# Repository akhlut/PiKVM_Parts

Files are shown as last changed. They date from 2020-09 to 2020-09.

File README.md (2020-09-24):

# PiKVM_Parts

Parts I've made for the PiKVM Project.  https://github.com/pikvm/pikvm

All parts are UNTESTED as of 9/23/2020

The idea behind this is to extend the core PiKVM and turn it into a 4-port switch.  4-Port HDMI switches are ubiquitous and inexpensive, making them a less than ideal candidate for designing a PCB around.  Given that GPIO pins can be assigned to specific functions it only makes sense to start building out a 4-port USB/ATX controller built on top of PiKVM.  Couple this with a way to mimic a button-press on an HDMI switch and we're in business.  

The USB and ATX PCB's stack on top of one another, minimizing the footprint.  The PCB's extend the width of the Pi, but not the length.  At some point I'll have to design a case.

Everything is drawn in EAGLE as it's the tool that I'm used to.

Questions?  
Ask on the discord server:  https://discord.com/channels/580094191938437144

Ask on the subreddit: https://old.reddit.com/r/pikvm/

Happy soldering!

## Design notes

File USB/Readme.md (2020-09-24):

PiKVM USB splitter design notes

AS OF 09232020 THIS DESIGN IS COMPLETE BUT UNTESTED!!!

This design uses Analog Devices ADUM3160 iCouplers to provide galvanic isolation between the OTG USB and the (4) external USB ports.

The GPIO pinout (v1.6) is as follows:

PORT A

    GPIO 17

PORT B

    GPIO 24

PORT C

    GPIO 11

PORT D

    GPIO 13

The OTG port can be switched to Ports A-D by holding GPIO HIGH.  

The OTG port does NOT supply power to the Raspberry Pi!  

Power the Pi by either: 

(1) Use the POWER-IN Port on the PCB to supply 5V to the PCB and Pi via the GPIO header

OR

(2) Use a POE hat to power the PI and use jumper cables to power the PCB @ AUX_PWR header

NEVER USE BOTH POWER OPTIONS AT ONCE!

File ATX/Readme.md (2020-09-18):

PiKVM ATX controller design notes

This design uses RJ45 connectors as they are cheap, compact, and ubiquitous.

The RJ45 pinout (v1.5) uses the T-568B pattern and is as follows:

    PIN_1 : W-O : POWER LED +

    PIN_2 : O-W : POWER LED -

    PIN_3 : W-G : IDE LED -

    PIN_4 : Bl-W : RESET -

    PIN_5 : W-Bl : RESET +

    PIN_6 : G-W : IDE LED +

    PIN_7 : W-Br : POWER +

    PIN_8 : Br-W : POWER -

-----

The GPIO pinout (v1) is as follows:

PORT A

    GPIO 03 - POWER

    GPIO 15 - RESET

    GPIO 04 - POWER LED

    GPIO 14 - IDE LED

PORT B

    GPIO 18 - POWER

    GPIO 27 - RESET

    GPIO 22 - POWER LED

    GPIO 23 - IDE LED

PORT C

    GPIO 10 - POWER

    GPIO 08 - RESET

    GPIO 09 - POWER LED

    GPIO 25 - IDE LED

PORT D

    GPIO 07 - POWER

    GPIO 06 - RESET

    GPIO 12 - POWER LED

    GPIO 05 - IDE LED

---

There is also a port to control an external switch.  A DC barrel jack is provided for connectivity.  There is no polarity, simply Common/Normally Open.  This is useful to control external HDMI/KVM switches.

EXTERNAL CONTROL PORT - GPIO 21

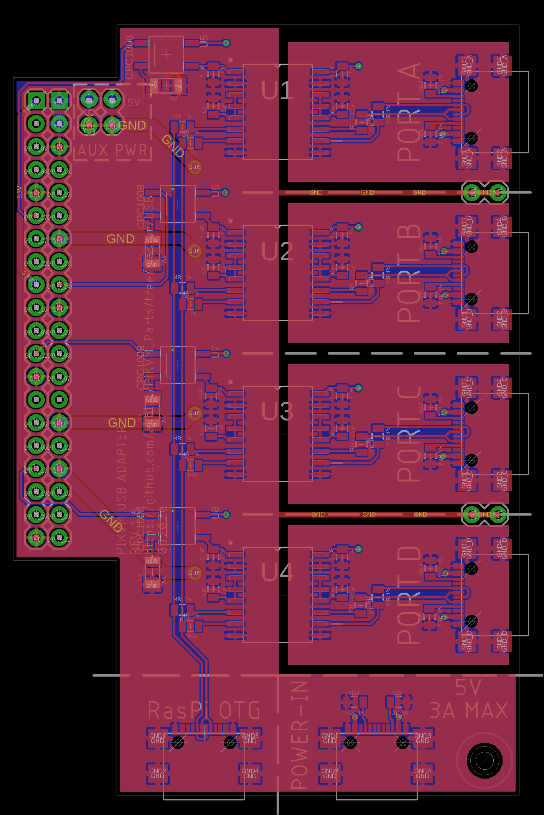
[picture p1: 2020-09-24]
USB/PiKVM_USB_Adapter v1.6.png

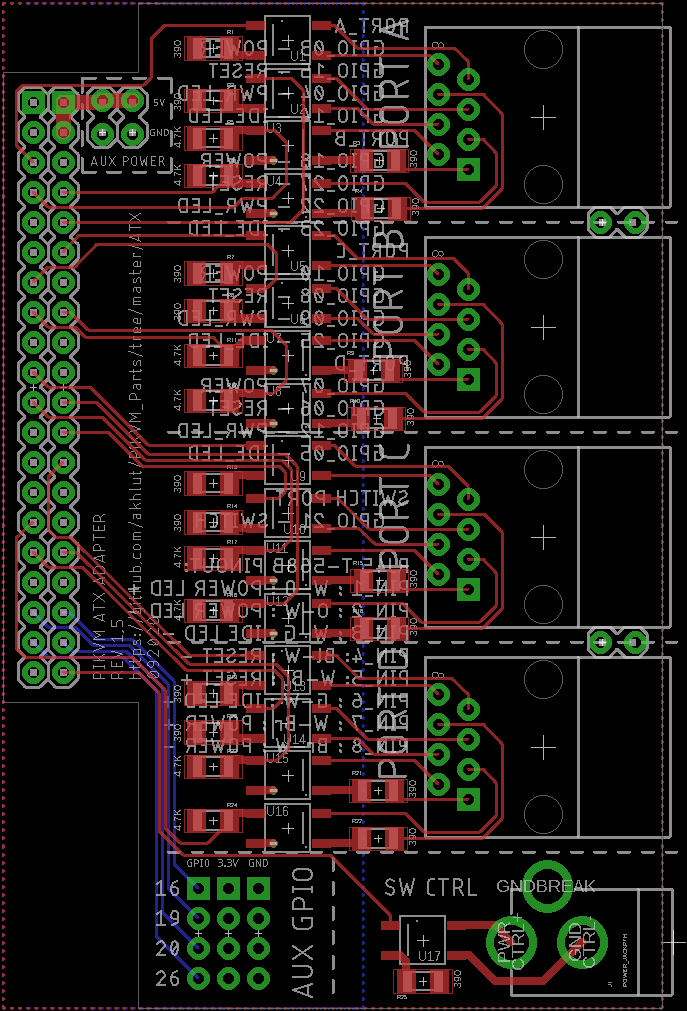
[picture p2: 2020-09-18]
ATX/PiKVM ATX Adapter v1.5.png

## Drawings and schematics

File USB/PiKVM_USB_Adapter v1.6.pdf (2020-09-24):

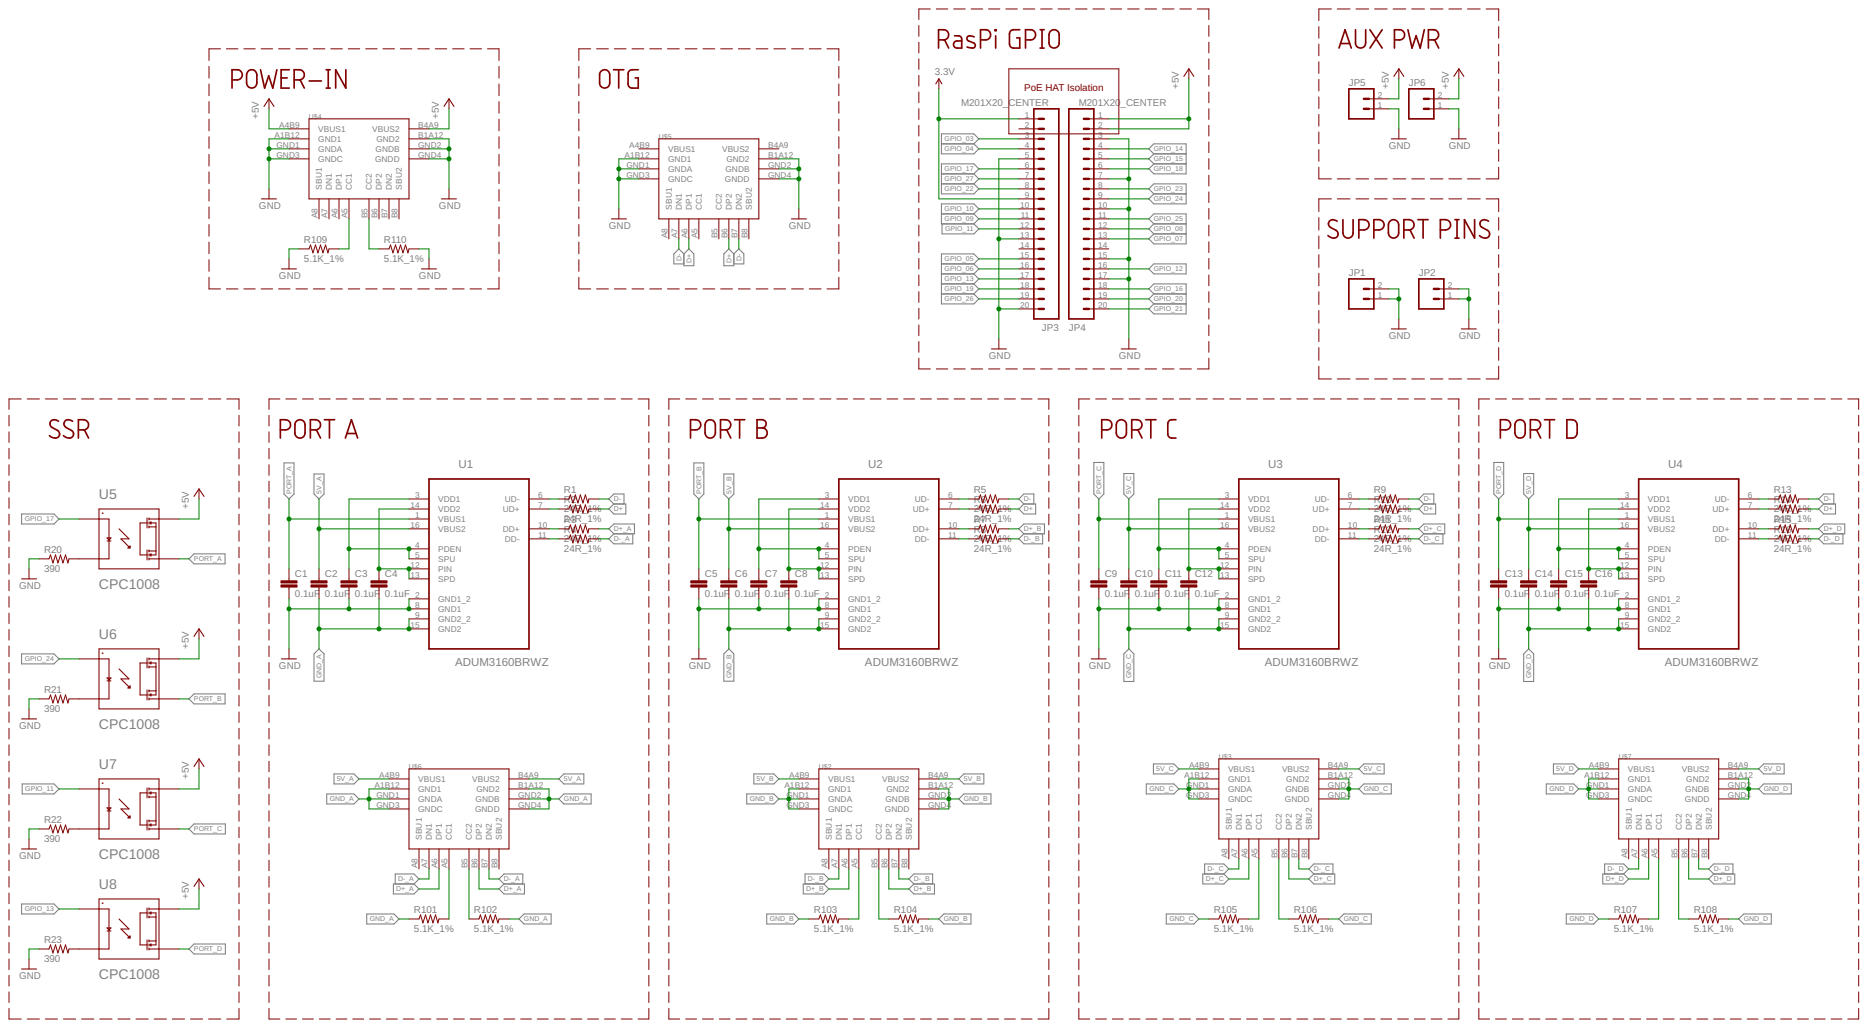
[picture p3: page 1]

10 | 10
11 | 11
12 | 12
13 | 13
14 | 14

16 | 16
17 | 17

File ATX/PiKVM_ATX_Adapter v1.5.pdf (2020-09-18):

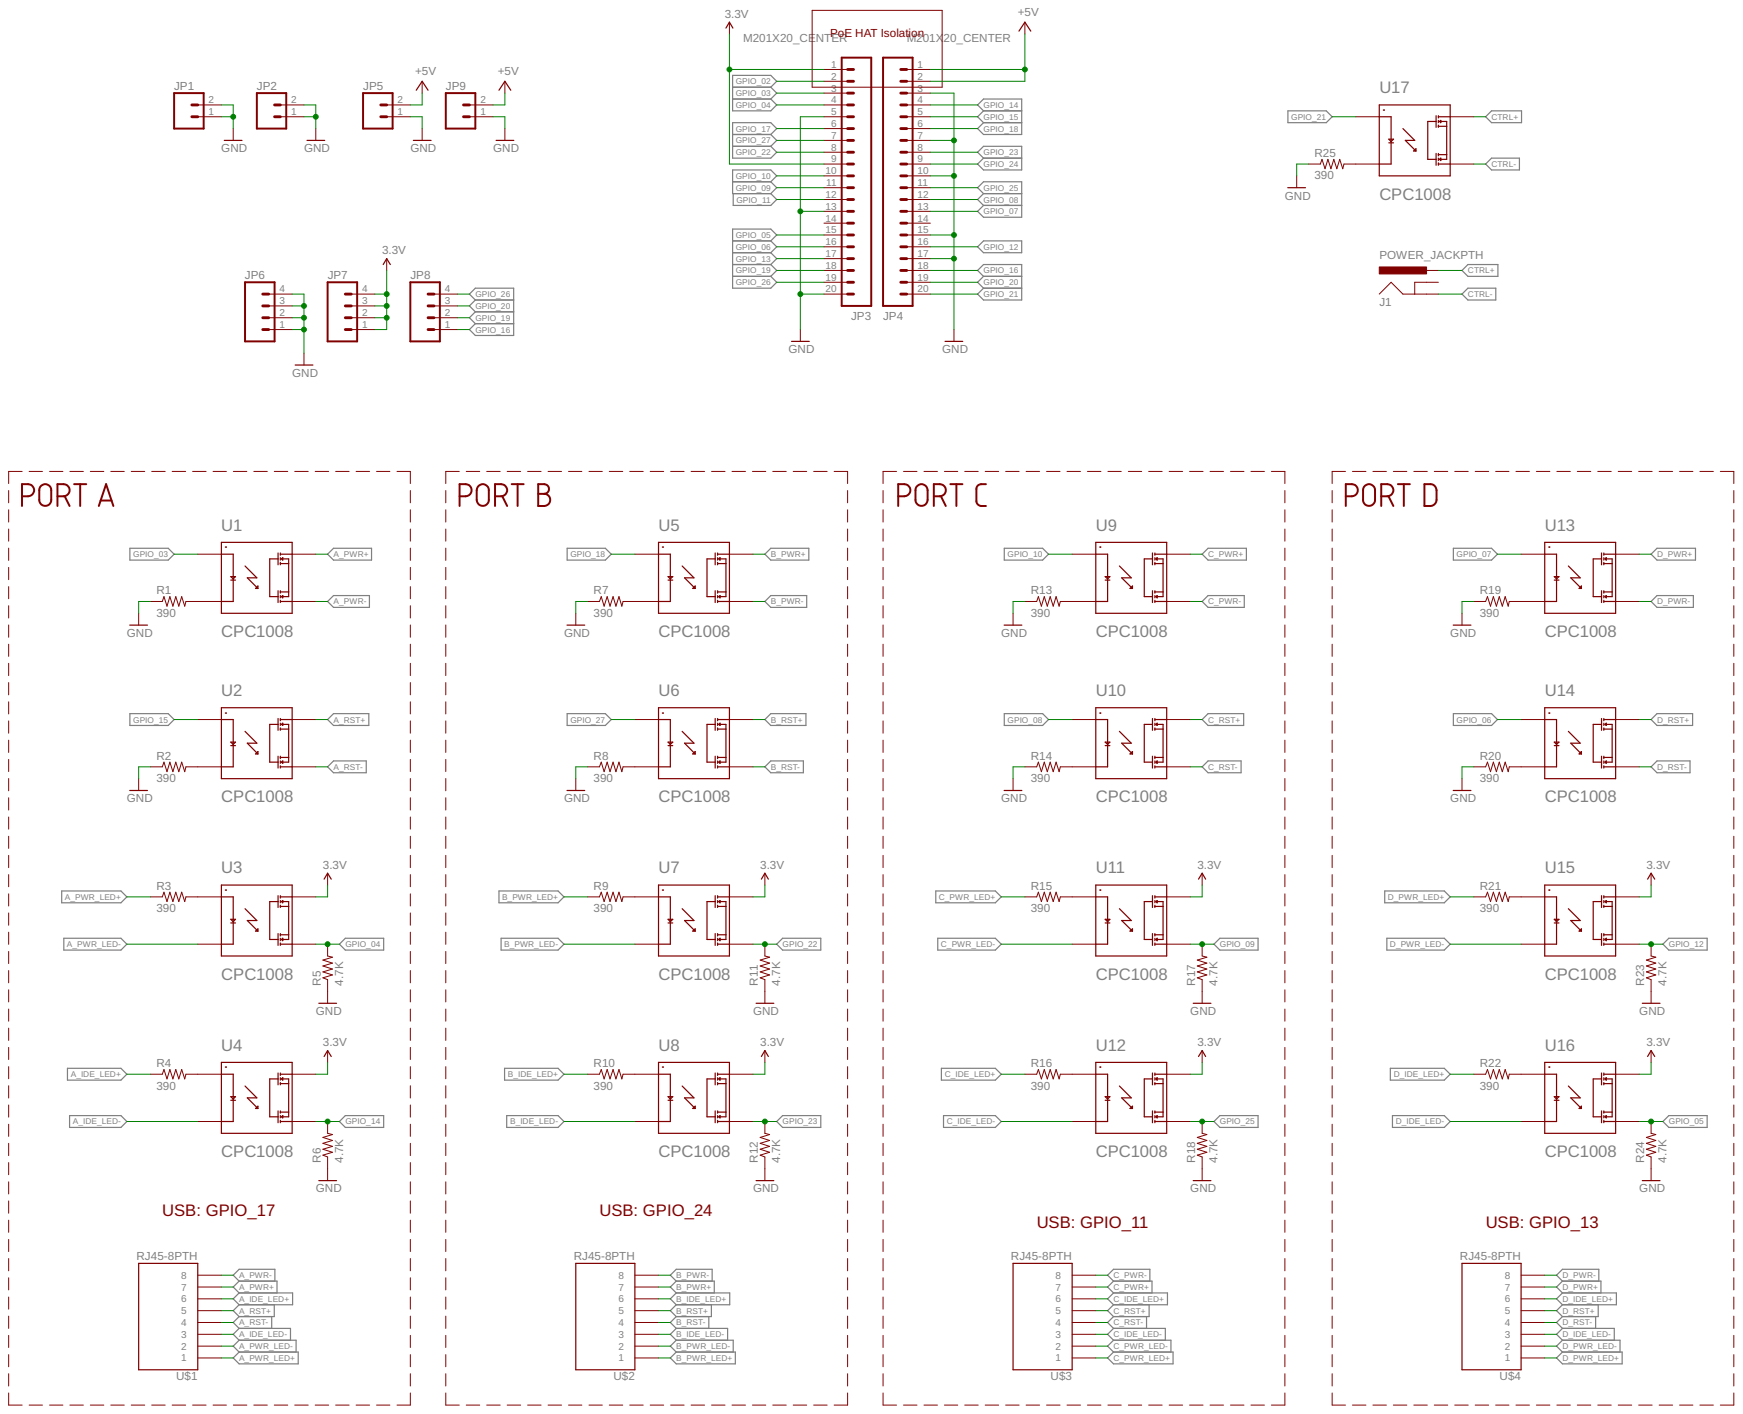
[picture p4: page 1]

13 | GPIO_08 GPIO_07

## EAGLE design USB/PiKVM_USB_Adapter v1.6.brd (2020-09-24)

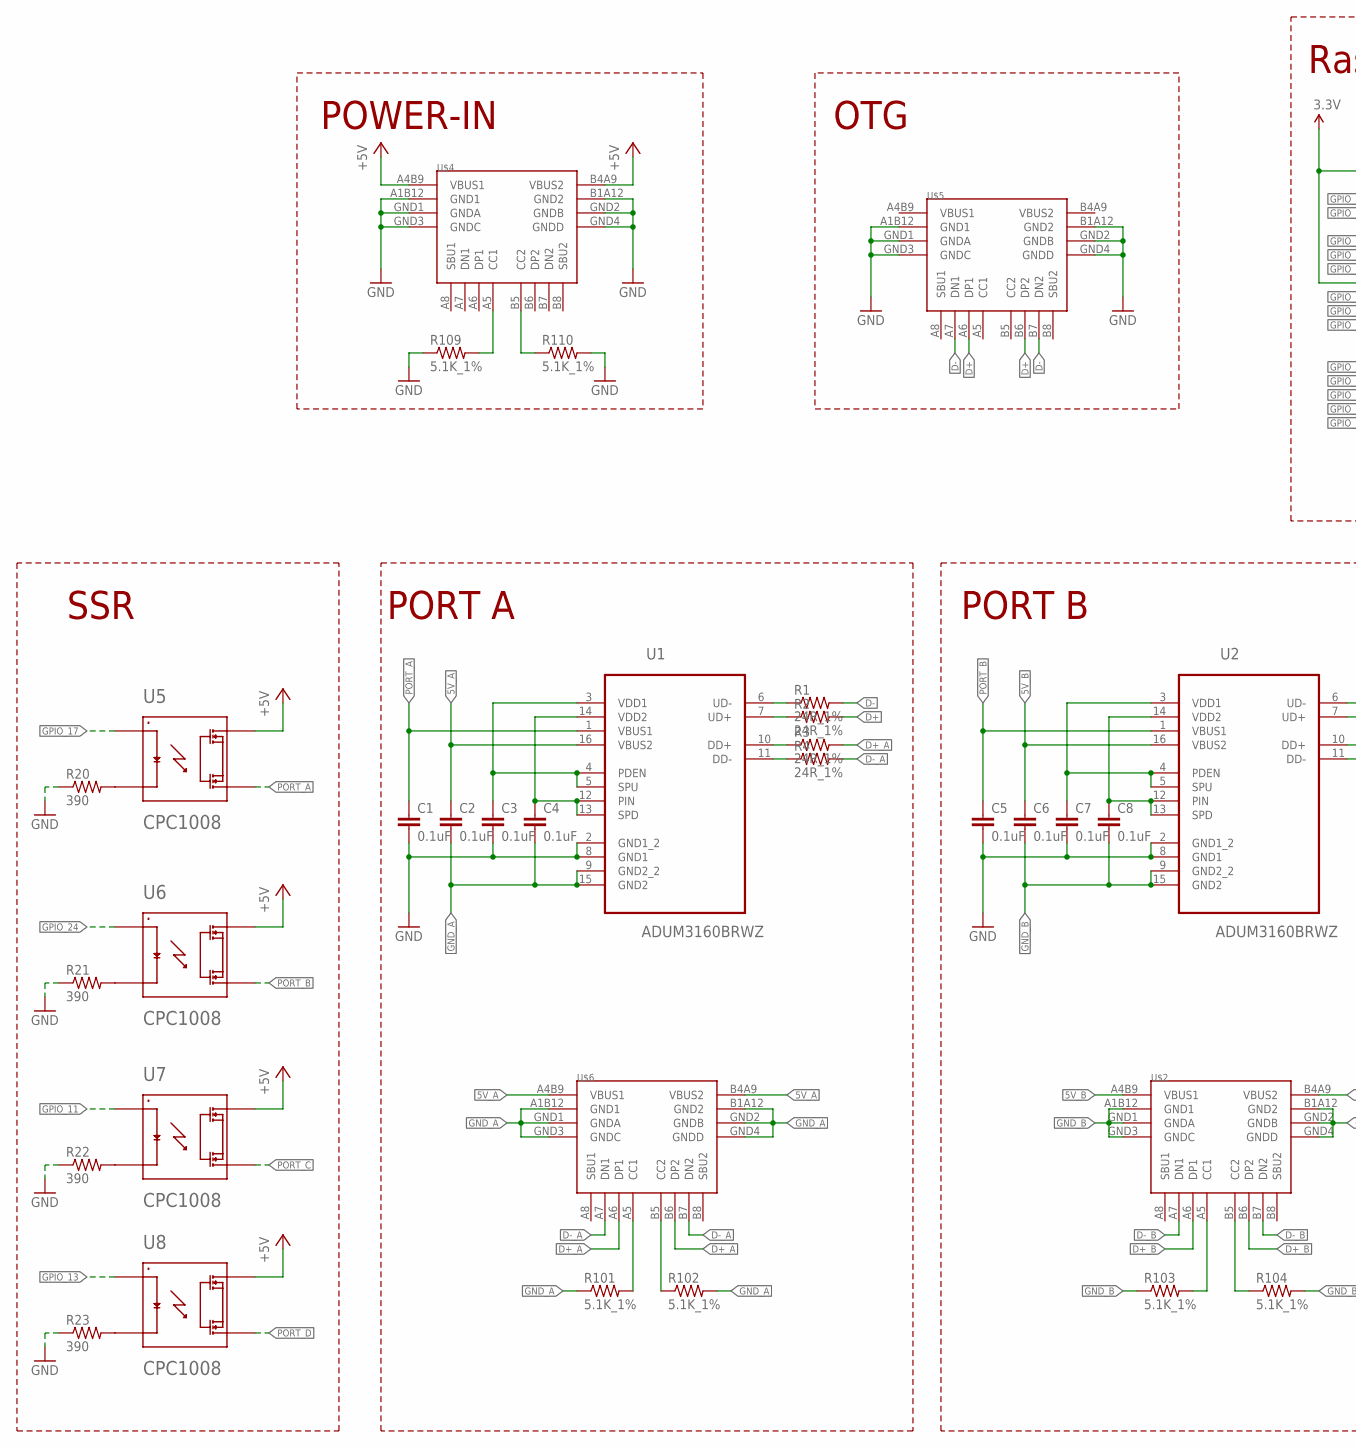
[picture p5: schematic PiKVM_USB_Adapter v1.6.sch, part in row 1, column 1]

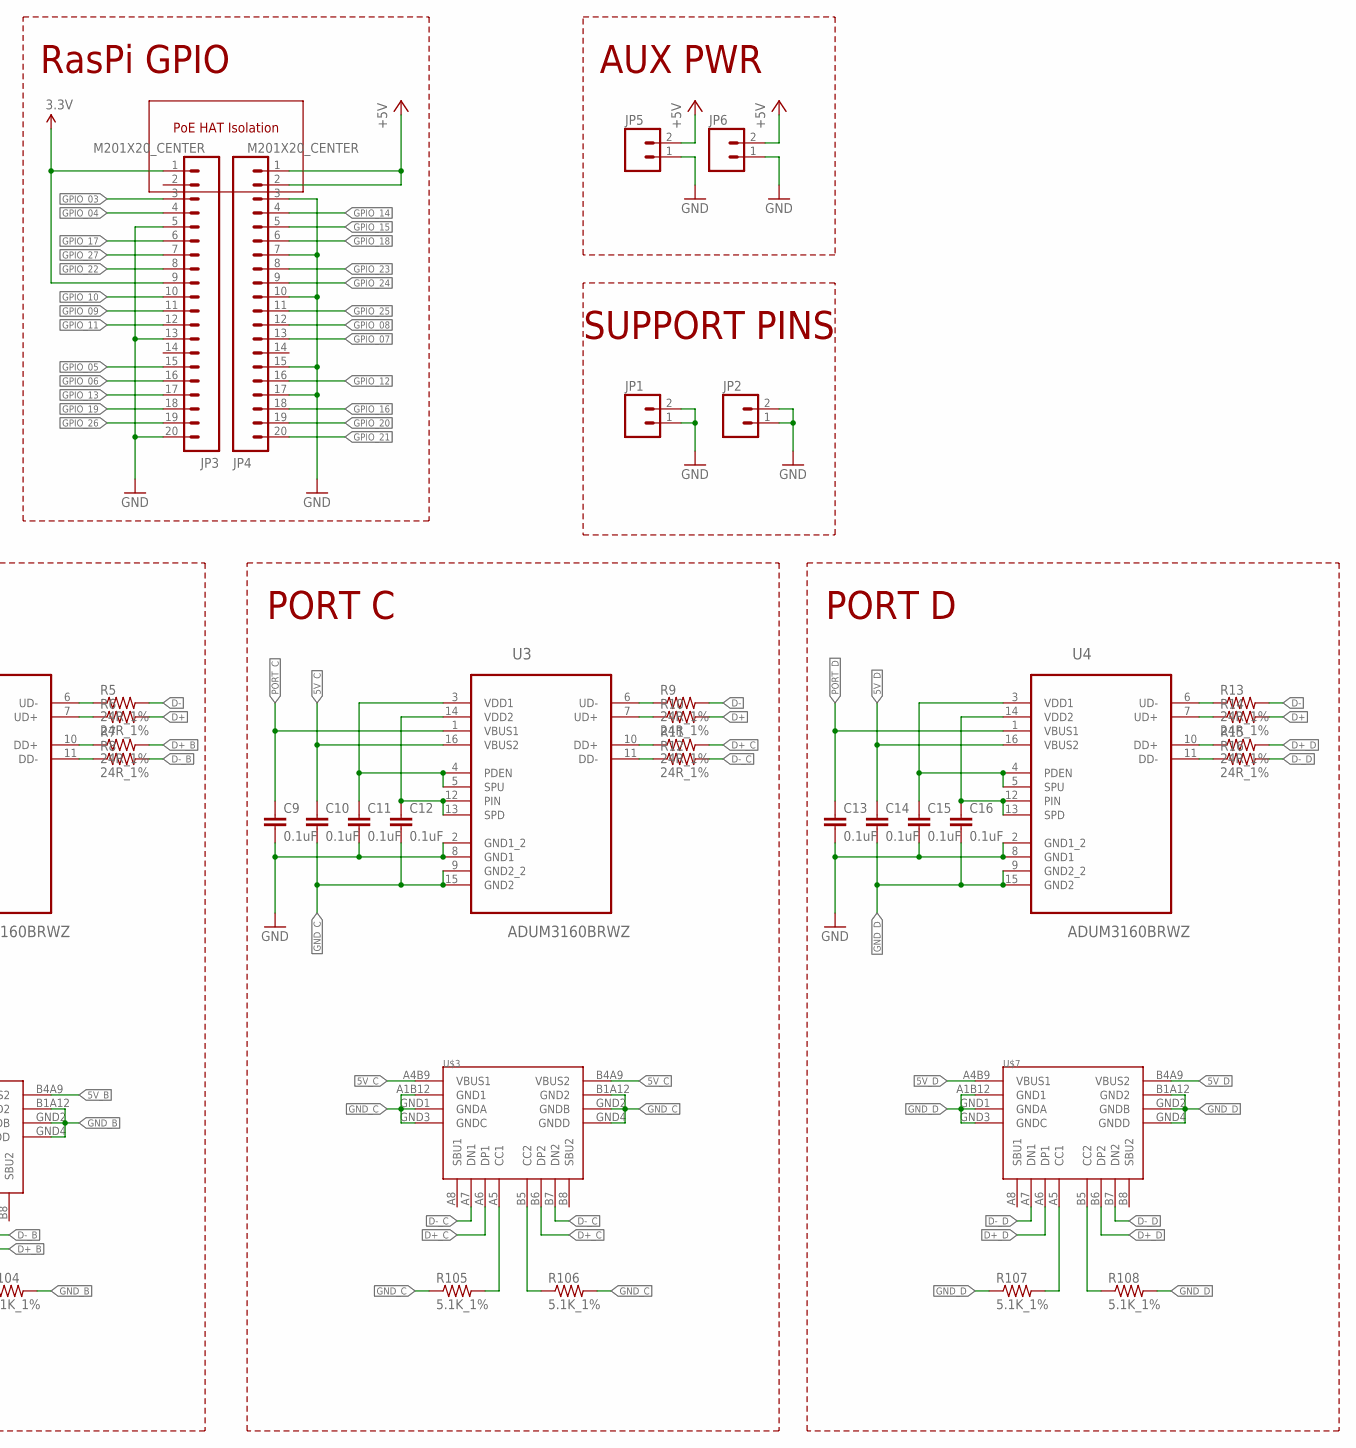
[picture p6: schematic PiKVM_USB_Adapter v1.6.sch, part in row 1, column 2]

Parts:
C1, C2, C3, C4, C5, C6, C7, C8, C9, C10, C11, C12, C13, C14, C15, C16: 0.1uF; 0805
JP1, JP2, JP5, JP6: M02LOCK; 1X02_LOCK
JP3, JP4: M201X20_CENTER; 1X20_CENTER
R1, R2, R3, R4, R5, R6, R7, R8, R9, R10, R11, R12, R13, R14, R15, R16: 24R_1%; 0805
R20, R21, R22, R23: 390; 1206
R101, R102, R103, R104, R105, R106, R107, R108, R109, R110: 5.1K_1%; 0805
U1, U2, U3, U4: ADUM3160BRWZ; SOIC127P1032X265-16N
U5, U6, U7, U8: CPC1008; SOP-4
U$2, U$3, U$4, U$5, U$6, U$7: USB4110GFA; GCT_USB4110GFA

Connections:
3.3V: JP3.1, JP3.9
5V_A: C2.1, U1.16 (VBUS2), U$6.A4B9 (VBUS1), U$6.B4A9 (VBUS2)
5V_B: C6.1, U2.16 (VBUS2), U$2.A4B9 (VBUS1), U$2.B4A9 (VBUS2)
5V_C: C10.1, U3.16 (VBUS2), U$3.A4B9 (VBUS1), U$3.B4A9 (VBUS2)
5V_D: C14.1, U4.16 (VBUS2), U$7.A4B9 (VBUS1), U$7.B4A9 (VBUS2)
+5V: JP4.1, JP4.2, JP5.2, JP6.2, U5.P$4 (4), U6.P$4 (4), U7.P$4 (4), U8.P$4 (4), U$4.A4B9 (VBUS1), U$4.B4A9 (VBUS2)
D+: R2.2, R6.2, R10.2, R14.2, U$5.A6 (DP1), U$5.B6 (DP2)
D+_A: R3.2, U$6.A6 (DP1), U$6.B6 (DP2)
D+_B: R7.2, U$2.A6 (DP1), U$2.B6 (DP2)
D+_C: R11.2, U$3.A6 (DP1), U$3.B6 (DP2)
D+_D: R15.2, U$7.A6 (DP1), U$7.B6 (DP2)
D-: R1.2, R5.2, R9.2, R13.2, U$5.A7 (DN1), U$5.B7 (DN2)
D-_A: R4.2, U$6.A7 (DN1), U$6.B7 (DN2)
D-_B: R8.2, U$2.A7 (DN1), U$2.B7 (DN2)
D-_C: R12.2, U$3.A7 (DN1), U$3.B7 (DN2)
D-_D: R16.2, U$7.A7 (DN1), U$7.B7 (DN2)
GND: C1.2, C3.2, C5.2, C7.2, C9.2, C11.2, C13.2, C15.2, JP1.1, JP1.2, JP2.1, JP2.2, JP3.5, JP3.13, JP3.20, JP4.3, JP4.7, JP4.10, JP4.15, JP4.17, JP5.1, JP6.1, R20.1, R21.1, R22.1, R23.1, R109.1, R110.2, U1.2 (GND1_2), U1.8 (GND1), U2.2 (GND1_2), U2.8 (GND1), U3.2 (GND1_2), U3.8 (GND1), U4.2 (GND1_2), U4.8 (GND1), U$4.A1B12 (GND1), U$4.B1A12 (GND2), U$4.GND1 (GNDA), U$4.GND2 (GNDB), U$4.GND3 (GNDC), U$4.GND4 (GNDD), U$5.A1B12 (GND1), U$5.B1A12 (GND2), U$5.GND1 (GNDA), U$5.GND2 (GNDB), U$5.GND3 (GNDC), U$5.GND4 (GNDD)
GND_A: C2.2, C4.2, R101.1, R102.2, U1.9 (GND2_2), U1.15 (GND2), U$6.A1B12 (GND1), U$6.B1A12 (GND2), U$6.GND1 (GNDA), U$6.GND2 (GNDB), U$6.GND3 (GNDC), U$6.GND4 (GNDD)
GND_B: C6.2, C8.2, R103.1, R104.2, U2.9 (GND2_2), U2.15 (GND2), U$2.A1B12 (GND1), U$2.B1A12 (GND2), U$2.GND1 (GNDA), U$2.GND2 (GNDB), U$2.GND3 (GNDC), U$2.GND4 (GNDD)
GND_C: C10.2, C12.2, R105.1, R106.2, U3.9 (GND2_2), U3.15 (GND2), U$3.A1B12 (GND1), U$3.B1A12 (GND2), U$3.GND1 (GNDA), U$3.GND2 (GNDB), U$3.GND3 (GNDC), U$3.GND4 (GNDD)
GND_D: C14.2, C16.2, R107.1, R108.2, U4.9 (GND2_2), U4.15 (GND2), U$7.A1B12 (GND1), U$7.B1A12 (GND2), U$7.GND1 (GNDA), U$7.GND2 (GNDB), U$7.GND3 (GNDC), U$7.GND4 (GNDD)
GPIO_03: JP3.3
GPIO_04: JP3.4
GPIO_05: JP3.15
GPIO_06: JP3.16
GPIO_07: JP4.13
GPIO_08: JP4.12
GPIO_09: JP3.11
GPIO_10: JP3.10
GPIO_11: JP3.12, U7.P$1 (1)
GPIO_12: JP4.16
GPIO_13: JP3.17, U8.P$1 (1)
GPIO_14: JP4.4
GPIO_15: JP4.5
GPIO_16: JP4.18
GPIO_17: JP3.6, U5.P$1 (1)
GPIO_18: JP4.6
GPIO_19: JP3.18
GPIO_20: JP4.19
GPIO_21: JP4.20
GPIO_22: JP3.8
GPIO_23: JP4.8
GPIO_24: JP4.9, U6.P$1 (1)
GPIO_25: JP4.11
GPIO_26: JP3.19
GPIO_27: JP3.7
unnamed: C8.1, U2.12 (PIN), U2.13 (SPD), U2.14 (VDD2)
unnamed: R5.1, U2.6 (UD-)
unnamed: R6.1, U2.7 (UD+)
unnamed: R7.1, U2.10 (DD+)
unnamed: R20.2, U5.P$2 (2)
unnamed: R8.1, U2.11 (DD-)
unnamed: C3.1, U1.3 (VDD1), U1.4 (PDEN), U1.5 (SPU)
unnamed: R101.2, U$6.A5 (CC1)
unnamed: C12.1, U3.12 (PIN), U3.13 (SPD), U3.14 (VDD2)
unnamed: R9.1, U3.6 (UD-)
unnamed: R10.1, U3.7 (UD+)
unnamed: R11.1, U3.10 (DD+)
unnamed: R12.1, U3.11 (DD-)
unnamed: R102.1, U$6.B5 (CC2)
unnamed: R108.1, U$7.B5 (CC2)
unnamed: C16.1, U4.12 (PIN), U4.13 (SPD), U4.14 (VDD2)
unnamed: R13.1, U4.6 (UD-)
unnamed: R107.2, U$7.A5 (CC1)
unnamed: C4.1, U1.12 (PIN), U1.13 (SPD), U1.14 (VDD2)
unnamed: R14.1, U4.7 (UD+)
unnamed: R15.1, U4.10 (DD+)
unnamed: R16.1, U4.11 (DD-)
unnamed: R1.1, U1.6 (UD-)
unnamed: R2.1, U1.7 (UD+)
unnamed: R3.1, U1.10 (DD+)
unnamed: R4.1, U1.11 (DD-)
unnamed: R105.2, U$3.A5 (CC1)
unnamed: R106.1, U$3.B5 (CC2)
unnamed: R21.2, U6.P$2 (2)
unnamed: R22.2, U7.P$2 (2)
unnamed: R23.2, U8.P$2 (2)
unnamed: C7.1, U2.3 (VDD1), U2.4 (PDEN), U2.5 (SPU)
unnamed: R104.1, U$2.B5 (CC2)
unnamed: C11.1, U3.3 (VDD1), U3.4 (PDEN), U3.5 (SPU)
unnamed: C15.1, U4.3 (VDD1), U4.4 (PDEN), U4.5 (SPU)
unnamed: R103.2, U$2.A5 (CC1)
unnamed: R109.2, U$4.A5 (CC1)
unnamed: R110.1, U$4.B5 (CC2)
PORT_A: C1.1, U1.1 (VBUS1), U5.P$3 (3)
PORT_B: C5.1, U2.1 (VBUS1), U6.P$3 (3)
PORT_C: C9.1, U3.1 (VBUS1), U7.P$3 (3)
PORT_D: C13.1, U4.1 (VBUS1), U8.P$3 (3)
VBUS1: U$5.A4B9 (VBUS1)
VBUS2: U$5.B4A9 (VBUS2)

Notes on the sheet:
PoE HAT Isolation
PORT A
PORT B
PORT C
PORT D
SSR
RasPi GPIO
OTG
POWER-IN
AUX PWR
SUPPORT PINS

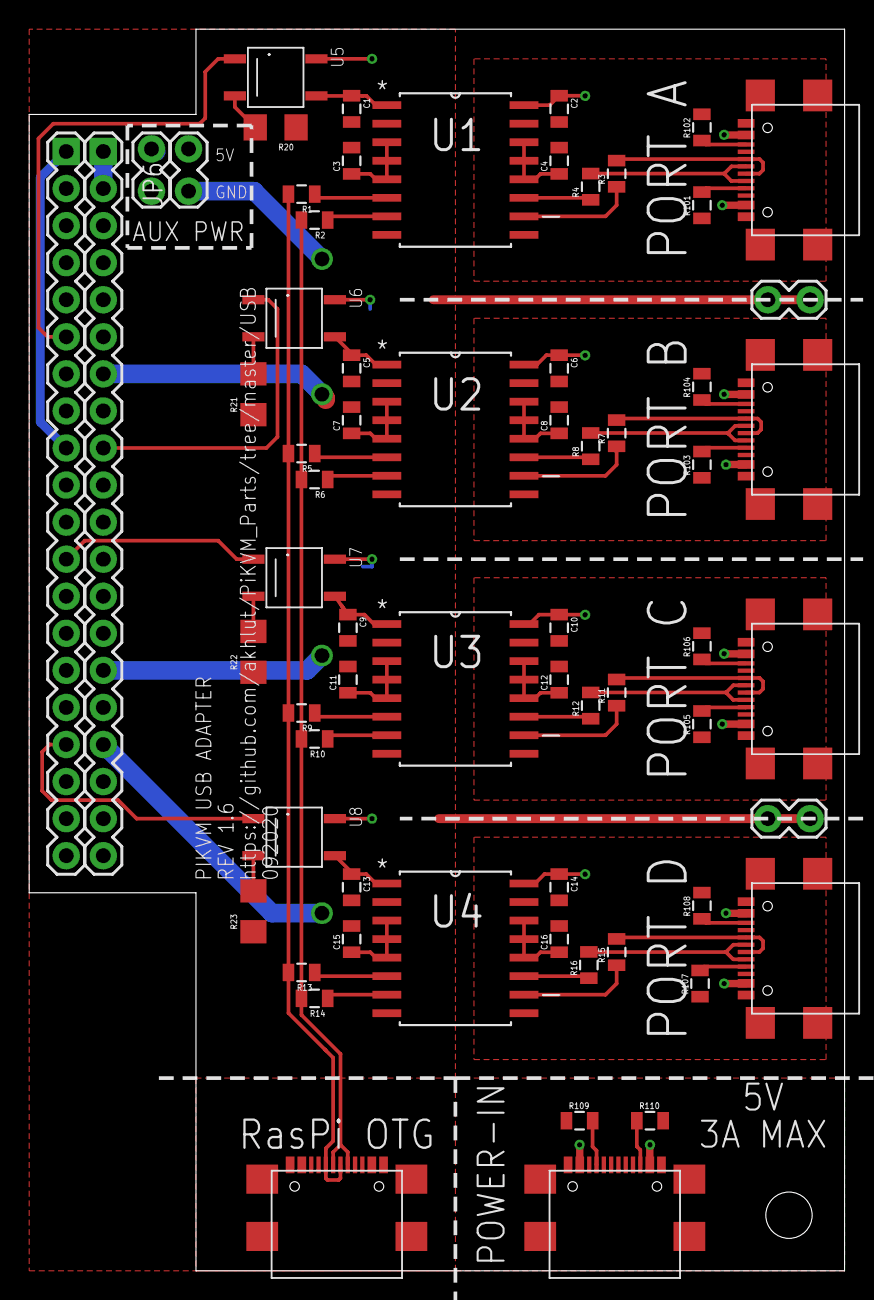
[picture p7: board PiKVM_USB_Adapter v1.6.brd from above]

Board: 2 copper layers, 55.9 x 85.1 mm, 66 parts (0 on the bottom side), 67 nets.

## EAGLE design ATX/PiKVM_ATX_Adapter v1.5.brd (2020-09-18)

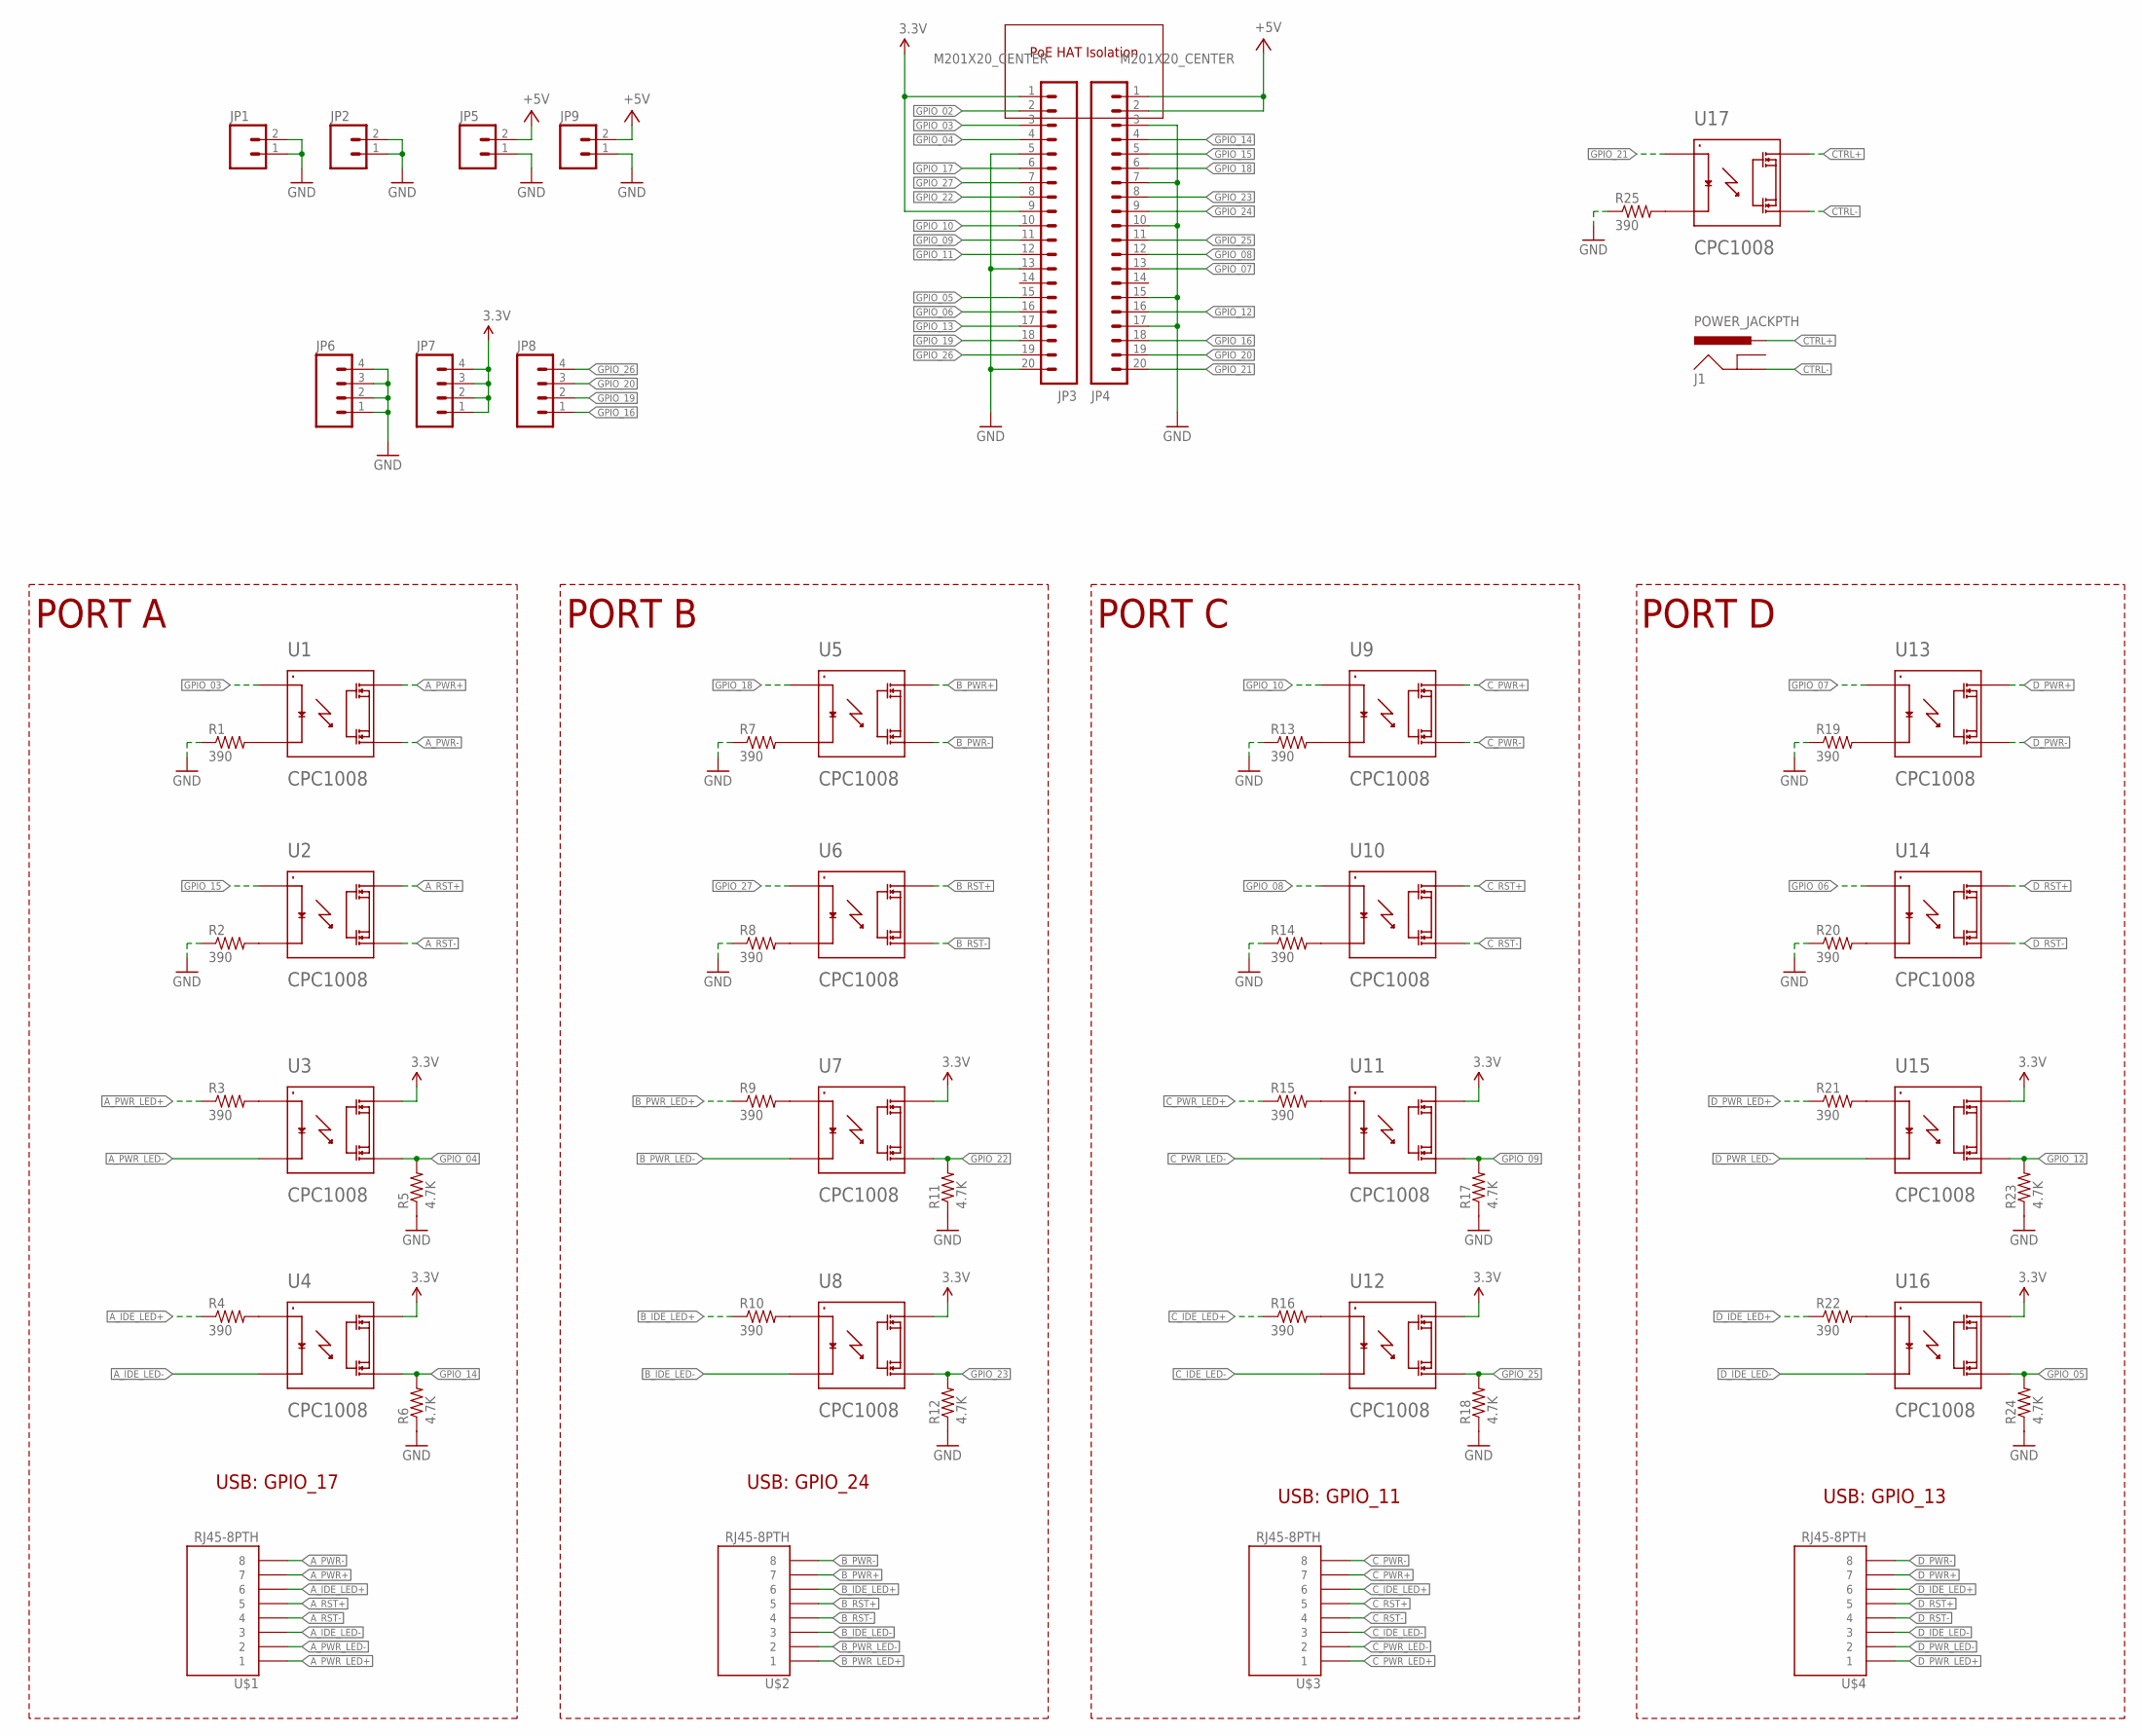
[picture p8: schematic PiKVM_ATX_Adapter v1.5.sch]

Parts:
J1: POWER_JACKPTH; POWER_JACK_PTH
JP1, JP2, JP5, JP9: M02LOCK; 1X02_LOCK
JP3, JP4: M201X20_CENTER; 1X20_CENTER
JP6, JP7, JP8: M04PTH; 1X04
R1, R2, R3, R4, R7, R8, R9, R10, R13, R14, R15, R16, R19, R20, R21, R22, R25: 390; 1206
R5, R6, R11, R12, R17, R18, R23, R24: 4.7K; 1206
U1, U2, U3, U4, U5, U6, U7, U8, U9, U10, U11, U12, U13, U14, U15, U16, U17: CPC1008; SOP-4
U$1, U$2, U$3, U$4: RJ45-8PTH; RJ45-8

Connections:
3.3V: JP3.1, JP3.9, JP7.1, JP7.2, JP7.3, JP7.4, U3.P$4 (4), U4.P$4 (4), U7.P$4 (4), U8.P$4 (4), U11.P$4 (4), U12.P$4 (4), U15.P$4 (4), U16.P$4 (4)
+5V: JP4.1, JP4.2, JP5.2, JP9.2
A_IDE_LED+: R4.1, U$1.6
A_IDE_LED-: U4.P$2 (2), U$1.3
A_PWR+: U1.P$4 (4), U$1.7
A_PWR-: U1.P$3 (3), U$1.8
A_PWR_LED+: R3.1, U$1.1
A_PWR_LED-: U3.P$2 (2), U$1.2
A_RST+: U2.P$4 (4), U$1.5
A_RST-: U2.P$3 (3), U$1.4
B_IDE_LED+: R10.1, U$2.6
B_IDE_LED-: U8.P$2 (2), U$2.3
B_PWR+: U5.P$4 (4), U$2.7
B_PWR-: U5.P$3 (3), U$2.8
B_PWR_LED+: R9.1, U$2.1
B_PWR_LED-: U7.P$2 (2), U$2.2
B_RST+: U6.P$4 (4), U$2.5
B_RST-: U6.P$3 (3), U$2.4
CTRL+: J1.PWR, U17.P$4 (4)
CTRL-: J1.GND, U17.P$3 (3)
C_IDE_LED+: R16.1, U$3.6
C_IDE_LED-: U12.P$2 (2), U$3.3
C_PWR+: U9.P$4 (4), U$3.7
C_PWR-: U9.P$3 (3), U$3.8
C_PWR_LED+: R15.1, U$3.1
C_PWR_LED-: U11.P$2 (2), U$3.2
C_RST+: U10.P$4 (4), U$3.5
C_RST-: U10.P$3 (3), U$3.4
D_IDE_LED+: R22.1, U$4.6
D_IDE_LED-: U16.P$2 (2), U$4.3
D_PWR+: U13.P$4 (4), U$4.7
D_PWR-: U13.P$3 (3), U$4.8
D_PWR_LED+: R21.1, U$4.1
D_PWR_LED-: U15.P$2 (2), U$4.2
D_RST+: U14.P$4 (4), U$4.5
D_RST-: U14.P$3 (3), U$4.4
GND: JP1.1, JP1.2, JP2.1, JP2.2, JP3.5, JP3.13, JP3.20, JP4.3, JP4.7, JP4.10, JP4.15, JP4.17, JP5.1, JP6.1, JP6.2, JP6.3, JP6.4, JP9.1, R1.1, R2.1, R5.1, R6.1, R7.1, R8.1, R11.1, R12.1, R13.1, R14.1, R17.1, R18.1, R19.1, R20.1, R23.1, R24.1, R25.1
GPIO_02: JP3.2
GPIO_03: JP3.3, U1.P$1 (1)
GPIO_04: JP3.4, R5.2, U3.P$3 (3)
GPIO_05: JP3.15, R24.2, U16.P$3 (3)
GPIO_06: JP3.16, U14.P$1 (1)
GPIO_07: JP4.13, U13.P$1 (1)
GPIO_08: JP4.12, U10.P$1 (1)
GPIO_09: JP3.11, R17.2, U11.P$3 (3)
GPIO_10: JP3.10, U9.P$1 (1)
GPIO_11: JP3.12
GPIO_12: JP4.16, R23.2, U15.P$3 (3)
GPIO_13: JP3.17
GPIO_14: JP4.4, R6.2, U4.P$3 (3)
GPIO_15: JP4.5, U2.P$1 (1)
GPIO_16: JP4.18, JP8.1
GPIO_17: JP3.6
GPIO_18: JP4.6, U5.P$1 (1)
GPIO_19: JP3.18, JP8.2
GPIO_20: JP4.19, JP8.3
GPIO_21: JP4.20, U17.P$1 (1)
GPIO_22: JP3.8, R11.2, U7.P$3 (3)
GPIO_23: JP4.8, R12.2, U8.P$3 (3)
GPIO_24: JP4.9
GPIO_25: JP4.11, R18.2, U12.P$3 (3)
GPIO_26: JP3.19, JP8.4
GPIO_27: JP3.7, U6.P$1 (1)
unnamed: R2.2, U2.P$2 (2)
unnamed: R3.2, U3.P$1 (1)
unnamed: R7.2, U5.P$2 (2)
unnamed: R1.2, U1.P$2 (2)
unnamed: R4.2, U4.P$1 (1)
unnamed: R8.2, U6.P$2 (2)
unnamed: R9.2, U7.P$1 (1)
unnamed: R10.2, U8.P$1 (1)
unnamed: R13.2, U9.P$2 (2)
unnamed: R14.2, U10.P$2 (2)
unnamed: R15.2, U11.P$1 (1)
unnamed: R16.2, U12.P$1 (1)
unnamed: R19.2, U13.P$2 (2)
unnamed: R20.2, U14.P$2 (2)
unnamed: R21.2, U15.P$1 (1)
unnamed: R22.2, U16.P$1 (1)
unnamed: R25.2, U17.P$2 (2)

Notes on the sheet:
PoE HAT Isolation
PORT A
PORT B
PORT C
PORT D
USB: GPIO_17
USB: GPIO_24
USB: GPIO_11
USB: GPIO_13

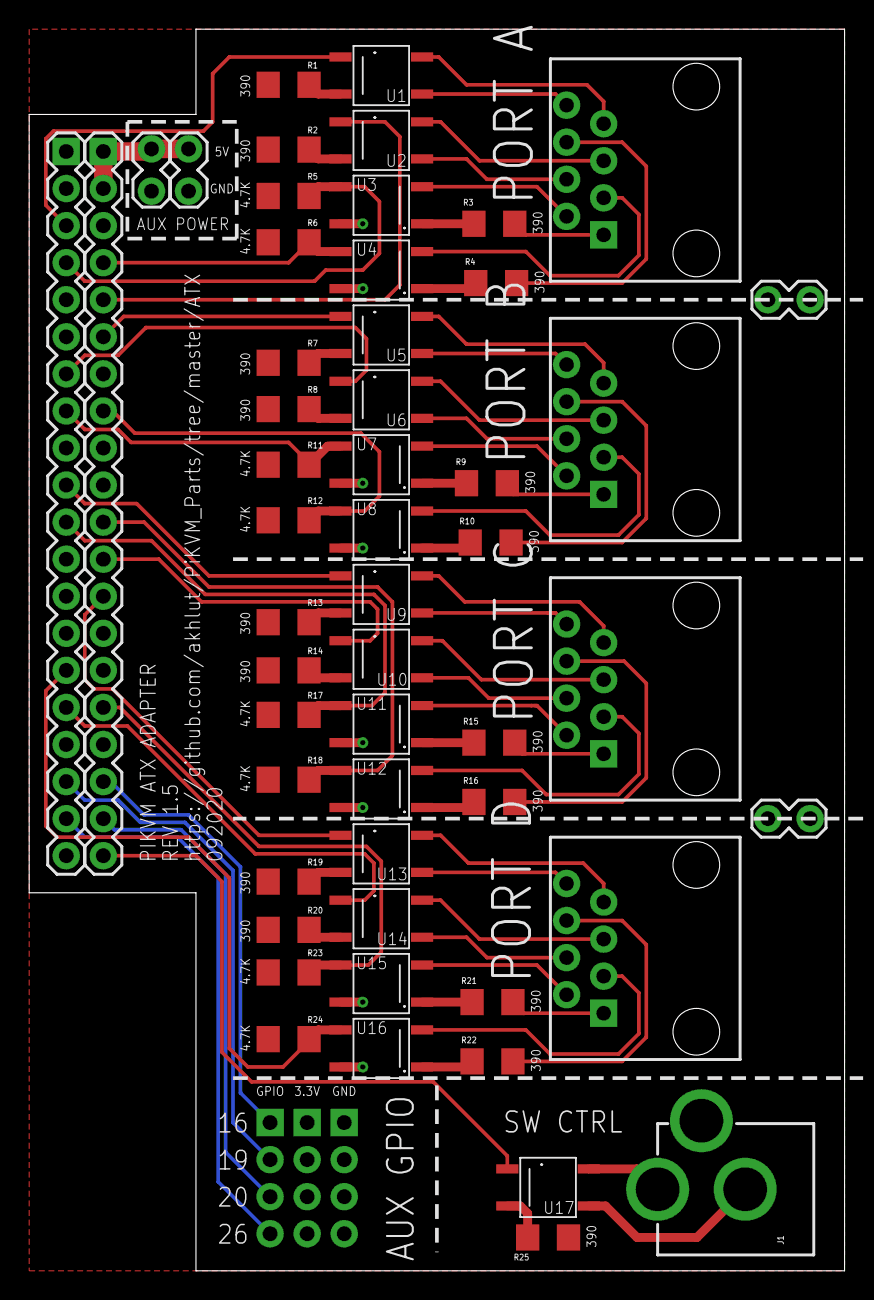
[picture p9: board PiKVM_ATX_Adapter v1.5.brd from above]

Board: 2 copper layers, 55.9 x 85.1 mm, 56 parts (0 on the bottom side), 75 nets.

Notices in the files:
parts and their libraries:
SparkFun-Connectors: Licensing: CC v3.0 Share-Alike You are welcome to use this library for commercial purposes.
